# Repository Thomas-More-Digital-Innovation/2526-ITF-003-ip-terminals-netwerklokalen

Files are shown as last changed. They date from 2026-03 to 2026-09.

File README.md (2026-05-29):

# IP Terminals

This repository contains the configuration, CAD designs, and build system for custom IP Terminal images used in Thomas More network classrooms. Based on **NixOS**, these images provide a robust, immutable environment for network debugging and configuration, housed in a custom 3D-printed enclosure.

---

## 🖨️ Part 1: Hardware & 3D Printing

To assemble the physical IP Terminal housing, you can 3D print the enclosure components. The 3D model files are located in the [3d](./3d) directory.

### 📦 Print Components & Files
* **Main Enclosure / Case**: Use the **[3d/ip-terminal.stl](./3d/ip-terminal.stl)** model.
* **LCD Buttons**: Use the **[3d/1.44lcd_button_stick.STL](./3d/1.44lcd_button_stick.STL)** model for the LCD buttons.

---

## 🏗️ Part 2: Software & RPI Image Building

This part covers the setup, compilation, installation, and deployment of the custom NixOS-based operating system on the Raspberry Pi 4.

### 🚀 Key Features
- **Immutable Environment**: Root filesystem is read-only by default (stateless).
- **Network Tools**: Pre-installed `nmap`, `dnsutils`, `traceroute`, `netcat`, and more.
- **Custom Configuration**: A built-in `config` tool to manage network settings via TUI.
- **Hardware Integration**: Support for LCD displays and custom service for IP monitoring.
- **Remote Management**: SSH enabled by default (User: `cisco`, Password: `cisco`).

### 🛠️ Getting Started

#### 1. Install Nix
To build these images, you need the Nix package manager:
```bash
sh <(curl -L https://nixos.org/nix/install) --daemon
```

#### 2. Configure Nix
Enable Flakes and Cross-Compilation by adding the following to `/etc/nix/nix.conf`:
```text
experimental-features = nix-command flakes
extra-platforms = aarch64-linux arm-linux i686-linux
```

### 🏗️ Building the Image
You can build different variants of the SD card image using the Nix flake.
*NOTE: Building can take a while. Some packages are downloaded from Cachix and others are built from source.*

| Variant | Command |
| :--- | :--- |
| **Standard SD** | `nix build .#sdImages.rpi4 --print-build-logs` |
| **Uncompressed** | `nix build .#sdImages.rpi4-uncompressed --print-build-logs` |
| **Immutable** | `nix build .#sdImages.rpi4-immutable --print-build-logs` |
| **Immutable (Uncompressed)** | `nix build .#sdImages.rpi4-immutable-uncompressed --print-build-logs` |

### 💾 Flashing to SD Card
Once built, the image will be in `result/sd-image/`. Replace `/dev/sdX` with your SD card device path.

#### Using `dd` (Standard)
```bash
# For compressed images (.img.zst)
zstdcat result/sd-image/*.img.zst | sudo dd of=/dev/sdX bs=4M status=progress conv=fsync

# For uncompressed images (.img)
sudo dd if=result/sd-image/*.img of=/dev/sdX bs=4M status=progress conv=fsync
```

#### Other Methods
- **Manual Decompression**: `zstd -d result/sd-image/nixos* -o rpi4-nixos.img`
- **Using Caligula**: `sudo caligula burn result/sd-image/nixos*`

### 🔄 Updating
For testing purposes, you can update the terminals over the network without reflashing the SD card.
*NOTE: This is only possible for mutable images.*

#### Update (via ssh)
```bash
nixos-rebuild switch --flake .#rpi4 --target-host root@<IP_OR_HOSTNAME> --option filter-syscalls false
```

#### Update (via sshpass)
```bash
sshpass -p "cisco" nixos-rebuild switch --flake .#rpi4 --target-host root@<IP_OR_HOSTNAME> --option filter-syscalls false
```

#### Update for next boot (via sshpass)
```bash
sshpass -p "cisco" nixos-rebuild boot --flake .#rpi4 --target-host root@<IP_OR_HOSTNAME> --option filter-syscalls false
```

### 🔐 Configuration

#### Password Generation
If you need to update the `hashedPassword` in `flake.nix`, generate a new hash using:
```bash
mkpasswd -m sha-512
```

#### Default Credentials
- **Username**: `cisco` (or `root` for mutable images)
- **Password**: `cisco`

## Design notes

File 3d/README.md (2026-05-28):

## 3D files
Requires Autodesk Inventor 2026
STL Exports are pvovided

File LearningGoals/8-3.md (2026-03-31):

# 8.3 You automate system administration tasks with Linux service management

## 1. Project Overview
The IP Terminal is a rackmounted network appliance based on a Raspberry Pi 4. It features an integrated SPI display, three physical buttons, and a joystick. The primary goal of this device is to provide a dedicated hardware interface for managing the Pi's networking configuration (IPv4, IPv6, DHCP, and DNS) directly from the rack, without requiring an external keyboard, monitor, or SSH access.

## 2. NixOS on Raspberry Pi
For this project, I chose NixOS as the operating system. NixOS's declarative nature is ideal for building specialized appliances like the IP Terminal. The entire system state, from the Linux kernel and hardware overlays (like SPI for the display) to the Python application and systemd services is defined in a single configuration file (`flake.nix`). This ensures that the terminal's behavior is consistent, reproducible, and easy to redeploy.

### 2.1 Why Nix Flakes?
While traditional NixOS uses "channels" (stateful pointers to package sets), I used Nix Flakes for this project to achieve full reproducibility.

*   **Traditional NixOS**: Relies on `nix-channel`, which can differ between machines. Building the same configuration on two different days might result in different package versions if the channel was updated in between.
*   **Nix Flakes**: Uses a `flake.lock` file that pins every dependency (including `nixpkgs` and hardware overlays) to a specific git commit hash. This ensures that the terminal build is identical every single time, regardless of which machine it is built on or when the build occurs.

To ensure the IP Terminal is always functional and accessible upon booting the Raspberry Pi, I configured a **systemd service** within the NixOS configuration. This service automatically starts the Python-based control application, which manages the terminal's networking settings through the connected LCD and physical controls.

## 3. Defining the systemd Service in NixOS

In NixOS, services are defined declaratively in the configuration. The `systemd.services` option allows for a structured way to define how an application should run, its dependencies, and its lifecycle.

### 3.1 What is `multi-user.target`?
In systemd, **targets** act as synchronization points for the boot process, roughly equivalent to "runlevels" in older Linux systems.

The **`multi-user.target`** is the standard target for a system that is fully booted and ready to support multiple users, either via local login or network services (like SSH). It represents a stable, non-graphical multi-user environment. 

I configured the `ip-terminal` service to be pulled in by this target (via the `wantedBy` option), ensuring it starts automatically during the final phase of the normal boot sequence once core services are active.

### Service Configuration:
```nix
systemd.services.ip-terminal = {
  description = "IP Terminal Main Service";
  after = [ "network-online.target" ];
  wants = [ "network-online.target" ];
  path = with pkgs; [ networkmanager dialog ncurses ];
  serviceConfig = {
    Type = "simple";
    ExecStart = "/opt/venv/bin/python /opt/ip-terminal-code/main.py";
    WorkingDirectory = "/opt/ip-terminal-code";
    Environment = [
      "PYTHONUNBUFFERED=1"
      "FONT_PATH=${pkgs.dejavu_fonts}/share/fonts/truetype/DejaVuSans.ttf"
    ];
    Restart = "always";
    User = "root";
  };
  wantedBy = [ "multi-user.target" ];
};
```

### Key Components of the Service:
*   **`after` & `wants`**: The service waits for `network-online.target`, ensuring the networking stack is ready before the application attempts to read or modify settings via `nmcli`.
*   **`ExecStart`**: Points to the Python interpreter within a custom virtual environment (`/opt/venv/bin/python`) and executes the entry point of the application (`main.py`).
*   **`Restart = "always"`**: If the Python application crashes, systemd will automatically restart it.
*   **`User = "root"`**: This defines that the service will run as the root user, having full administrative privileges over the system. This is necessary because the application must interact with physical GPIO pins and use `nmcli` to modify system-wide network configuration.
*   **`Environment`**: This allows passing environment variables to the service. For the IP Terminal, I configured `PYTHONUNBUFFERED=1` to ensure that Python logs are sent immediately to `journalctl` without buffering, and `FONT_PATH` to tell the application where to find the fonts required for the LCD display.

## 4. The Python Application Logic

The application has multiple modes. When started by the systemd service (without arguments), it defaults to **Hardware Mode**, which utilizes the Waveshare LCD HAT and its joystick for input. However, it can also be run in **TUI Mode**, which uses the terminal for input and output.

### Application Entry Point:
```python
if __name__ == "__main__":
    parser = argparse.ArgumentParser(description="IP Terminal Configurator")
    parser.add_argument(
        "--tui",
        action="store_true",
        help="Run in TUI (dialog) mode instead of hardware mode.",
    )
    args = parser.parse_args()

    if args.tui:
        run_tui()
    else:
        run_hardware()
```

By running this as a systemd service, the terminal becomes a dedicated appliance. Users can configure the IP address, prefix, gateway, and DNS directly from the device's physical interface as soon as it powers on, without needing a keyboard or a network connection first.

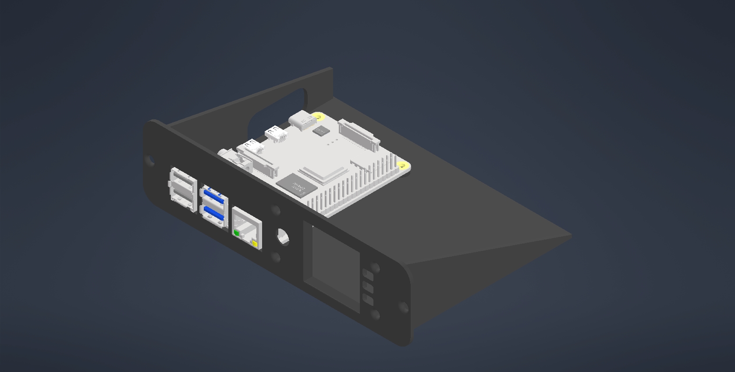
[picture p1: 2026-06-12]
3d/PI-RACK-MOUNT.jpg

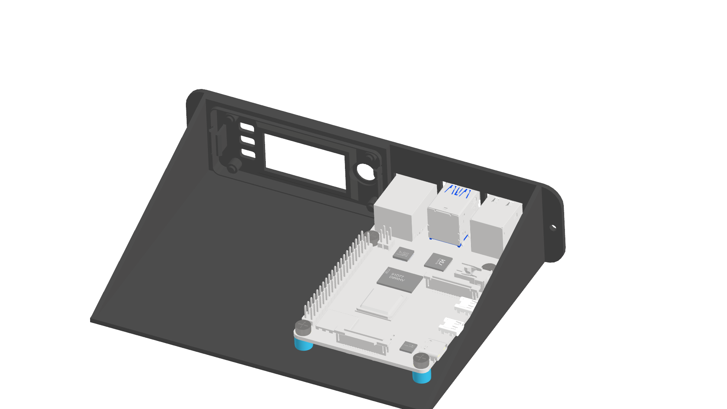
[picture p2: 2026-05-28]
3d/PI-RACK-MOUNT.png

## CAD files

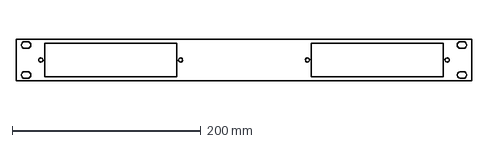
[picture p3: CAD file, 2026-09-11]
3d/WoodPanel.dxf
482.6 x 44.0 mm

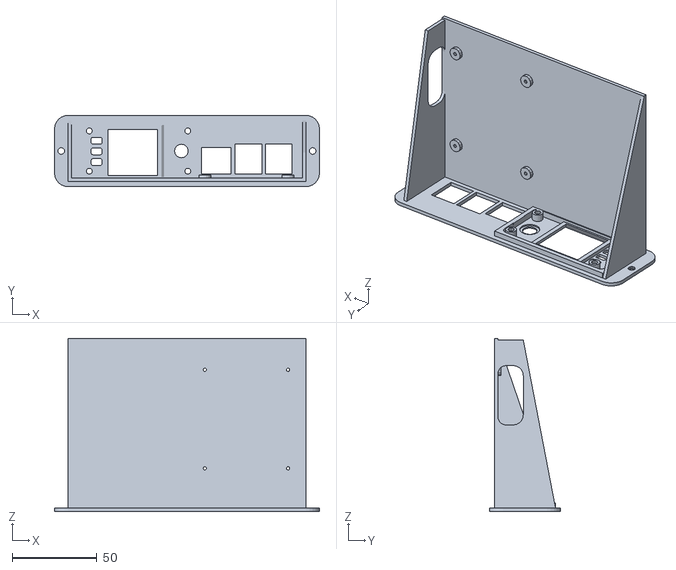
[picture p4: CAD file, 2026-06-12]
3d/ip-terminal.stl
156.0 x 42.0 x 102.0

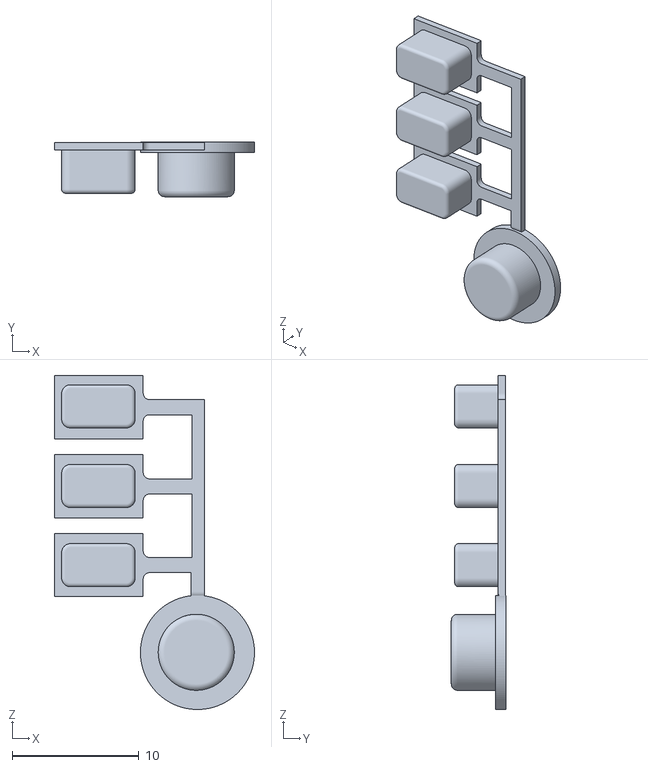
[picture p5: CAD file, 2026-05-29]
3d/1.44lcd_button_stick.STL
15.8 x 4.30 x 26.3

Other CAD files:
3d/1.44lcd_cap.ipt
3d/1.44lcd_cap_2.ipt
3d/Assembly1.iam
3d/Assembly2.iam
3d/BoltM3-PI-2.ipt
3d/BoltM3-PI.ipt
3d/M3 hex nut v6.ipt
3d/OldVersions/1.44lcd_cap.0003.ipt
3d/OldVersions/1.44lcd_cap_2.0016.ipt
3d/OldVersions/Assembly1.0021.iam
3d/OldVersions/Assembly2.0016.iam
3d/OldVersions/PI-RACK-MOUNT.0012.iam
3d/OldVersions/RPI_HOUSING2.0018.ipt
3d/OldVersions/Raspberry Pi 4 Model B.0001.iam
3d/OldVersions/Spacer.0002.ipt
3d/OldVersions/WoodPanel.0006.ipt
3d/PI-RACK-MOUNT.iam
3d/RPI_HOUSING2.ipt
3d/Raspberry Pi 4 Model B.iam
3d/Raspberry Pi 4 Model B.ipt
3d/Raspberry Pi 4 Model B/2.54 mm DUPONT MALE PIN HEADER, IO, 2X20, RPi4ModelB.ipt
3d/Raspberry Pi 4 Model B/2.54 mm DUPONT MALE PIN HEADER, IO, 2X20, RPi4ModelB_1.ipt
3d/Raspberry Pi 4 Model B/2.54 mm DUPONT MALE PIN HEADER, IO, 2X20, RPi4ModelB_10.ipt
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

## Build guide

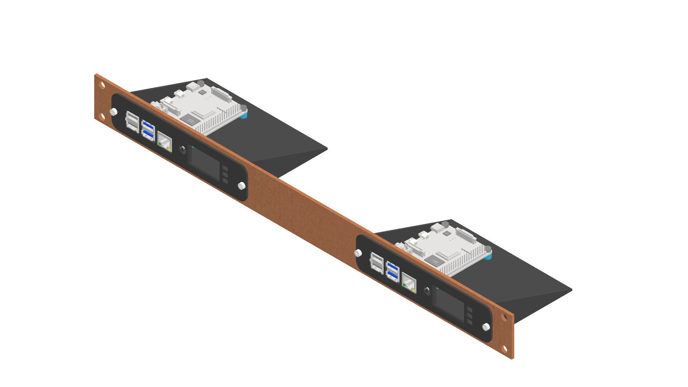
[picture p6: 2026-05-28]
3d/Assembly1.png

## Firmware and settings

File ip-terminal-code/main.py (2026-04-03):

#!/usr/bin/env python3
"""
IP Terminal Configurator

Two operating modes, selected at launch:
  (default)  Hardware mode – rotary encoder + I2C LCD (Raspberry Pi)
  --tui      TUI mode      – dialog-based interface for SSH / serial console

Usage:
  python3 main.py          # hardware mode
  python3 main.py --tui    # TUI mode
"""

import argparse
import ipaddress
import os
import subprocess
import sys
import textwrap
import time


# ---------------------------------------------------------------------------
# Shared state  (module-level so both modes can read/write it)
# ---------------------------------------------------------------------------

ip_octets      = [192, 168, 1, 1]
subnet_prefix  = 16                 # CIDR prefix length (0-32)
gateway_octets = [192, 168, 1, 1]
dns_octets     = [1,   1,   1, 1]
use_dhcp       = False              # True = ipv4.method auto

MENU_OPTIONS    = ["IP address", "Subnet prefix", "Gateway", "DNS"]
MENU_COUNT      = len(MENU_OPTIONS)
CONNECTION_NAME = "end0"
ipv6_method     = "auto"            # "auto", "dhcp", "manual", "disabled"
IPV6_METHODS    = ["auto", "dhcp", "manual", "disabled"]
IPV6_NAMES      = {
    "auto": "Automatic",
    "dhcp": "Automatic (DHCP only)",
    "manual": "Manual",
    "disabled": "Disabled"
}


# ---------------------------------------------------------------------------
# Shared helpers
# ---------------------------------------------------------------------------

def octets_str(octs):
    return ".".join(str(o) for o in octs)


def field_octets(field):
    """Return the mutable octet list for a field index (0=IP, 2=GW, 3=DNS)."""
    if field == 0:
        return ip_octets
    elif field == 2:
        return gateway_octets
    else:
        return dns_octets


def field_value_str(field):
    """Human-readable current value for a field index."""
    if field == 0:
        return "DHCP" if use_dhcp else octets_str(ip_octets)
    if field == 1:
        return "DHCP" if use_dhcp else f"/{subnet_prefix}"
    if field == 2:
        return "DHCP" if use_dhcp else octets_str(gateway_octets)
    return octets_str(dns_octets)  # field 3: DNS


def auto_gateway_from_ip():
    """Set gateway_octets to the first host address (network + 1) of the current subnet."""
    try:
        network = ipaddress.IPv4Network(
            f"{octets_str(ip_octets)}/{subnet_prefix}", strict=False
        )
        gw = network.network_address + 1
        gateway_octets[:] = list(gw.packed)
    except Exception:
        pass


# ---------------------------------------------------------------------------
# Network helpers (shared)
# ---------------------------------------------------------------------------

def get_network_settings():
    """Populate shared state from nmcli / systemd-resolved."""
    global subnet_prefix, use_dhcp, ipv6_method

    try:
        result = subprocess.run(
            ["nmcli", "-g", "IP4.ADDRESS", "connection", "show", CONNECTION_NAME],
            capture_output=True, text=True, check=True,
        )
        addr = result.stdout.strip().split("\n")[0]
        if addr and "/" in addr:
            ip_part, prefix_part = addr.split("/")
            ip_octets[:]  = [int(x) for x in ip_part.split(".")]
            subnet_prefix = int(prefix_part)
    except Exception as e:
        sys.stderr.write(f"Error in get_network_settings (IP4.ADDRESS): {e}\n")

    try:
        result = subprocess.run(
            ["nmcli", "-g", "IP4.GATEWAY", "connection", "show", CONNECTION_NAME],
            capture_output=True, text=True, check=True,
        )
        gw = result.stdout.strip()
        if gw and gw != "--":
            gateway_octets[:] = [int(x) for x in gw.split(".")]
    except Exception as e:
        sys.stderr.write(f"Error in get_network_settings (IP4.GATEWAY): {e}\n")

    try:
        # First try to get the configured static DNS
        result = subprocess.run(
            ["nmcli", "-g", "ipv4.dns", "connection", "show", CONNECTION_NAME],
            capture_output=True, text=True, check=True,
        )
        dns_output = result.stdout.strip()

        # If no static DNS, try the active runtime DNS (from DHCP)
        if not dns_output or dns_output == "--":
            result = subprocess.run(
                ["nmcli", "-g", "IP4.DNS", "connection", "show", CONNECTION_NAME],
                capture_output=True, text=True, check=True,
            )
            dns_output = result.stdout.strip()

        if dns_output and dns_output != "--":
            # nmcli may return multiple DNS servers separated by commas or spaces
            dns_str = dns_output.replace(",", " ").split()[0]
            if dns_str and "." in dns_str:
                dns_octets[:] = [int(x) for x in dns_str.split(".")]
    except Exception as e:
        sys.stderr.write(f"Error in get_network_settings (DNS recovery): {e}\n")

    try:
        result = subprocess.run(
            ["nmcli", "-g", "ipv4.method", "connection", "show", CONNECTION_NAME],
            capture_output=True, text=True, check=True,
        )
        use_dhcp = result.stdout.strip() == "auto"
    except Exception as e:
        sys.stderr.write(f"Error in get_network_settings (ipv4.method): {e}\n")

    try:
        result = subprocess.run(
            ["nmcli", "-g", "ipv6.method", "connection", "show", CONNECTION_NAME],
            capture_output=True, text=True, check=True,
        )
        meth = result.stdout.strip()
        if meth in IPV6_METHODS:
            ipv6_method = meth
    except Exception as e:
        sys.stderr.write(f"Error in get_network_settings (ipv6.method): {e}\n")


def get_live_ips():
    """Return a list of lines representing currently active IPv4 and IPv6 addresses."""
    lines = []
    for family, field in (("IPv4", "IP4.ADDRESS"), ("IPv6", "IP6.ADDRESS")):
        try:
            result = subprocess.run(
                ["nmcli", "-g", field, "connection", "show", CONNECTION_NAME],
                capture_output=True, text=True, check=True,
            )
            output = result.stdout.strip()
            if not output or output == "--":
                lines.append(f"{family}: (none)")
                continue

            # nmcli may return multiple addresses on multiple lines or separated by |
            raw_addrs = []
            for line in output.splitlines():
                raw_addrs.extend(line.split(" | "))

            addrs = [a.strip().replace("\\:", ":") for a in raw_addrs if a.strip()]
            if addrs:
                lines.append(f"{family}:")
                for a in addrs:
                    lines.append(f" - {a}")
            else:
                lines.append(f"{family}: (none)")
        except Exception:
            lines.append(f"{family}: error")
    return lines


def apply_all_settings():
    """Apply IP/prefix, gateway and DNS all at once."""
    ipv6_args = ["ipv6.method", ipv6_method]
    if ipv6_method != "manual":
        ipv6_args += ["ipv6.addresses", "", "ipv6.gateway", "", "ipv6.dns", "", "ipv6.ignore-auto-dns", "no"]

    if use_dhcp:
        dns_str = octets_str(dns_octets)
        subprocess.run(
            ["nmcli", "connection", "modify", CONNECTION_NAME,
             "ipv4.method", "auto",
             "ipv4.addresses", "",
             "ipv4.gateway", "",
             "ipv4.dns", dns_str,
             "ipv4.ignore-auto-dns", "yes"] + ipv6_args,
            check=True, capture_output=True,
        )
    else:
        cidr = f"{octets_str(ip_octets)}/{subnet_prefix}"
        dns_str = octets_str(dns_octets)
        subprocess.run(
            ["nmcli", "connection", "modify", CONNECTION_NAME,
             "ipv4.method", "manual",
             "ipv4.addresses", cidr,
             "ipv4.gateway", octets_str(gateway_octets),
             "ipv4.dns", dns_str,
             "ipv4.ignore-auto-dns", "yes"] + ipv6_args,
            check=True, capture_output=True,
        )
    subprocess.run(["nmcli", "con", "up", CONNECTION_NAME], check=True, capture_output=True)


def apply_settings(field):
    """Apply the current value of *field* via nmcli."""
    if field in (0, 1):
        if use_dhcp:
            subprocess.run(
                ["nmcli", "connection", "modify", CONNECTION_NAME,
                 "ipv4.method", "auto", "ipv4.addresses", "", "ipv4.gateway", "", "ipv4.dns", "", "ipv4.ignore-auto-dns", "no"],
                check=True, capture_output=True,
            )
        else:
            cidr = f"{octets_str(ip_octets)}/{subnet_prefix}"
            subprocess.run(
                ["nmcli", "connection", "modify", CONNECTION_NAME,
                 "ipv4.method", "manual", "ipv4.addresses", cidr],
                check=True, capture_output=True,
            )
        subprocess.run(["nmcli", "con", "up", CONNECTION_NAME], check=True, capture_output=True)

    elif field == 2:  # Gateway (static only – no-op in DHCP mode)
        if not use_dhcp:
            subprocess.run(
                ["nmcli", "connection", "modify", CONNECTION_NAME,
                 "ipv4.gateway", octets_str(gateway_octets)],
                check=True, capture_output=True,
            )
            subprocess.run(["nmcli", "con", "up", CONNECTION_NAME], check=True, capture_output=True)

    else:  # DNS (field 3)
        dns_str = octets_str(dns_octets)
        subprocess.run(
            ["nmcli", "connection", "modify", CONNECTION_NAME,
             "ipv4.dns", dns_str, "ipv4.ignore-auto-dns", "yes"],
            check=True, capture_output=True,
        )
        subprocess.run(["nmcli", "con", "up", CONNECTION_NAME], check=True, capture_output=True)


# ---------------------------------------------------------------------------
# Hardware mode  –  rotary encoder + I2C LCD
# ---------------------------------------------------------------------------
# ABCD
def run_hardware():
    """Main loop for the physical rotary-encoder + I2C-LCD interface."""
    global subnet_prefix, use_dhcp, ipv6_method

    import RPi.GPIO as GPIO
    from PIL import Image, ImageDraw, ImageFont
    from lcd_driver import ST7735

    # Pin assignments (Waveshare 1.44inch LCD HAT)
    UP_PIN    = 6
    DOWN_PIN  = 19
    LEFT_PIN  = 5
    RIGHT_PIN = 26
    PRESS_PIN = 13
    KEY1_PIN  = 21
    KEY2_PIN  = 20
    KEY3_PIN  = 16

    lcd = ST7735()

    # Load fonts (try environment variable first, then fall back to default)
    env_font = os.environ.get("FONT_PATH")
    font = ImageFont.load_default()
    title_font = font
    header_font = font

    if env_font:
        try:
            # Main font for menu items (increased from default ~8 to 13)
            font = ImageFont.truetype(env_font, 13)
            # Bold/Larger font for titles (15)
            title_font = ImageFont.truetype(env_font, 15)
            # Smaller header/footer if needed
            header_font = ImageFont.truetype(env_font, 11)
            print(f"DEBUG: Successfully loaded font from FONT_PATH: {env_font}")
        except Exception as e:
            print(f"DEBUG: Could not load TTF font from FONT_PATH ({env_font}), falling back to default.")
    else:
        print("DEBUG: FONT_PATH not set, falling back to default low-resolution font.")

    HW_MENU       = ["IPv4 Settings", "IPv6 Settings", "DNS Settings", "View IPs"]
    HW_MENU_COUNT = len(HW_MENU)
    IP_SUBMENU    = ["Mode", "IP Address", "Prefix", "Gateway", "Apply", "<- Back"]
    IPV6_SUBMENU  = ["Mode", "Apply", "<- Back"]

    # Local UI state
    mode             = "menu"   # "menu" | "ip_mode" | "view_ip" | "edit"
    menu_index       = 0
    edit_field       = 0        # field index into MENU_OPTIONS (0-3)
    state_index      = 0        # octet being edited (0-3)
    ip_mode_index    = 0
    ipv6_mode_index  = 0
    live_ip          = []       # List of (text, color) tuples
    view_ip_scroll   = 0
    edit_return_mode = "menu"

    # Color palette
    COLOR_BG      = (0, 0, 0)
    COLOR_TEXT    = (255, 255, 255)
    COLOR_HIGHLIGHT = (0, 0, 255) # Blue
    COLOR_ACCENT  = (0, 255, 255) # Cyan
    COLOR_YELLOW  = (255, 255, 0) # Yellow

    # ---- LCD helpers ----

    def update_display():
        image = Image.new("RGB", (128, 128), COLOR_BG)
        draw = ImageDraw.Draw(image)

        if mode == "menu":
            draw.text((5, 5), "Main Menu", font=title_font, fill=COLOR_ACCENT)
            draw.line((5, 23, 123, 23), fill=COLOR_ACCENT)
            for i, item in enumerate(HW_MENU):
                y = 28 + i * 20
                prefix = "> " if i == menu_index else "  "
                color = COLOR_HIGHLIGHT if i == menu_index else COLOR_TEXT
                draw.text((5, y), f"{prefix}{item}", font=font, fill=color)

        elif mode == "ip_mode":
            draw.text((5, 5), "IPv4 Settings", font=title_font, fill=COLOR_ACCENT)
            draw.line((5, 23, 123, 23), fill=COLOR_ACCENT)
            current_y = 28
            for i, item in enumerate(IP_SUBMENU):
                prefix = "> " if i == ip_mode_index else "  "
                color = COLOR_HIGHLIGHT if i == ip_mode_index else COLOR_TEXT

                display_text = item
                if i == 0: # Mode
                    display_text = f"Mode: {'DHCP' if use_dhcp else 'Manual'}"
                elif i in (1, 2, 3) and use_dhcp:
                    color = (100, 100, 100) # Grayed out
                lines = textwrap.wrap(f"{prefix}{display_text}", width=18)

                for j, line in enumerate(lines):
                    draw.text((5, current_y), line, font=font, fill=color)
                    current_y += 15 # Line height for font size 13

        elif mode == "ipv6_mode":
            draw.text((5, 5), "IPv6 Settings", font=title_font, fill=COLOR_ACCENT)
            draw.line((5, 23, 123, 23), fill=COLOR_ACCENT)
            current_y = 28
            for i, item in enumerate(IPV6_SUBMENU):
                prefix = "> " if i == ipv6_mode_index else "  "
                color = COLOR_HIGHLIGHT if i == ipv6_mode_index else COLOR_TEXT

                if i == 0: # Mode
                    label = f"{prefix}Mode:"
                    val_text = IPV6_NAMES.get(ipv6_method, ipv6_method)
                    lines = [label]
                    # Indent the value lines
                    wrapped_val = textwrap.wrap(val_text, width=14)
                    for w_line in wrapped_val:
                        lines.append(f"    {w_line}")
                else:
                    display_text = item
                    lines = textwrap.wrap(f"{prefix}{display_text}", width=18)

                for line in lines:
                    draw.text((5, current_y), line, font=font, fill=color)
                    current_y += 15

        elif mode == "view_ip":
            draw.text((5, 5), "IP Addresses", font=title_font, fill=COLOR_ACCENT)
            draw.line((5, 23, 123, 23), fill=COLOR_ACCENT)

            # Draw up to 7 lines from the scroll position
            for i in range(7):
                idx = view_ip_scroll + i
                if idx >= len(live_ip):
                    break
                line, color = live_ip[idx]
                y = 28 + i * 12
                draw.text((5, y), line, font=header_font, fill=color)

            draw.text((5, 115), "Press=Exit, +/-=Scroll", font=header_font, fill=COLOR_HIGHLIGHT)

        elif mode == "edit":
            labels = {0: "Edit IP", 1: "Edit prefix", 2: "Edit GW", 3: "Edit DNS"}
            draw.text((5, 5), labels[edit_field], font=title_font, fill=COLOR_ACCENT)
            draw.line((5, 23, 123, 23), fill=COLOR_ACCENT)

            if edit_field == 1:
                draw.text((5, 50), f"Value: /{subnet_prefix}", font=font, fill=COLOR_TEXT)
            else:
                octs = field_octets(edit_field)
                val_str = ""
                for i, o in enumerate(octs):
                    if i == state_index:
                        val_str += f"[{o}] "
                    else:
                        val_str += f"{o} "
                draw.text((5, 50), val_str.strip(), font=font, fill=COLOR_TEXT)

            draw.text((5, 105), "Press to confirm", font=header_font, fill=COLOR_HIGHLIGHT)

        print(f"DEBUG: update_display (mode={mode}, menu={menu_index}, edit={edit_field})")
        lcd.display(image)

    def do_apply_all():
        image = Image.new("RGB", (128, 128), COLOR_BG)
        draw = ImageDraw.Draw(image)
        draw.text((5, 50), "Applying...", font=font, fill=COLOR_ACCENT)
        lcd.display(image)

        try:
            apply_all_settings()
            draw.text((5, 80), "Done!", font=font, fill=(0, 255, 0))
            lcd.display(image)
            time.sleep(2)
        except Exception as exc:
            print(f"apply error: {exc}")
            draw.text((5, 75), "Error!", font=font, fill=(255, 0, 0))
            err_msg = str(exc)[:22]
            draw.text((5, 95), err_msg, font=header_font, fill=(255, 0, 0))
            lcd.display(image)
            time.sleep(3)

    # ---- GPIO setup ----
    GPIO.setmode(GPIO.BCM)
    for pin in [UP_PIN, DOWN_PIN, LEFT_PIN, RIGHT_PIN, PRESS_PIN, KEY1_PIN, KEY2_PIN, KEY3_PIN]:
        GPIO.setup(pin, GPIO.IN, pull_up_down=GPIO.PUD_UP)

    get_network_settings()
    update_display()
    print("IP configurator ready. Joystick to navigate, KEY1/Press to select.")

    display_dirty    = False

    def get_input_state():
        return {
            "up": GPIO.input(UP_PIN) == 0,
            "down": GPIO.input(DOWN_PIN) == 0,
            "left": GPIO.input(LEFT_PIN) == 0,
            "right": GPIO.input(RIGHT_PIN) == 0,
            "press": GPIO.input(PRESS_PIN) == 0,
            "key1": GPIO.input(KEY1_PIN) == 0,
            "key2": GPIO.input(KEY2_PIN) == 0,
            "key3": GPIO.input(KEY3_PIN) == 0,
        }

    last_input = get_input_state()

    up_hold_start = 0
    up_last_repeat = 0
    down_hold_start = 0
    down_last_repeat = 0

    REPEAT_DELAY = 0.4

    try:
        while True:
            current_input = get_input_state()
            now = time.time()

            # Detect edge (button press)
            press_detected = False
            key3_detected = False
            direction = 0
            back_detected = False
            left_detected = False
            right_detected = False

            # UP with repeat and acceleration
            if current_input["up"]:
                if not last_input["up"]:
                    direction = -1
                    up_hold_start = now
                    up_last_repeat = now
                    print("DEBUG: Joystick UP (press)")
                elif now - up_hold_start > REPEAT_DELAY:
                    hold_duration = now - up_hold_start
                    # Accelerate interval and step
                    if hold_duration > 1.5:
                        current_interval = 0.05
                        direction = -20
                    elif hold_duration > 0.2:
                        current_interval = 0.04
                        direction = -5
                    else:
                        current_interval = 0.1
                        direction = -1

                    if now - up_last_repeat > current_interval:
                        up_last_repeat = now
                        # direction is already set
                    else:
                        direction = 0 # Don't act if interval not reached
            else:
                up_hold_start = 0

            # DOWN with repeat and acceleration
            if current_input["down"]:
                if not last_input["down"]:
                    direction = 1
                    down_hold_start = now
                    down_last_repeat = now
                    print("DEBUG: Joystick DOWN (press)")
                elif now - down_hold_start > REPEAT_DELAY:
                    hold_duration = now - down_hold_start
                    # Accelerate interval and step
                    if hold_duration > 3:
                        current_interval = 0.05
                        direction = 10
                    elif hold_duration > 1.5:
                        current_interval = 0.04
                        direction = 5
                    else:
                        current_interval = 0.1
                        direction = 1

                    if now - down_last_repeat > current_interval:
                        down_last_repeat = now
                        # direction is already set
                    else:
                        direction = 0 # Don't act if interval not reached
            else:
                down_hold_start = 0

            if current_input["left"] and not last_input["left"]:
                left_detected = True
                print("DEBUG: Joystick LEFT")
            if current_input["right"] and not last_input["right"]:
                right_detected = True
                print("DEBUG: Joystick RIGHT")

            if current_input["press"] and not last_input["press"]:
                press_detected = True
                print("DEBUG: Joystick PRESS")
            if current_input["key1"] and not last_input["key1"]:
                direction = -1
                print("DEBUG: KEY1 (UP)")
            if current_input["key2"] and not last_input["key2"]:
                direction = 1
                print("DEBUG: KEY2 (DOWN)")
            if current_input["key3"] and not last_input["key3"]:
                key3_detected = True
                print("DEBUG: KEY3 (Quick Action)")
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

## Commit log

2026-03-06 Enable I2C
2026-05-28 Upload 3D files
    [1.44lcd_cap.0003.ipt, 1.44lcd_cap_2.0014.ipt, 2.54 mm DUPONT MALE PIN HEADER, IO, 2X20, RPi4ModelB.ipt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]
2026-05-29 Add LCD buttons
    [1.44lcd_button_stick.STL]
2026-05-29 Make display hole bottom bigger and add chamfers
    [1.44lcd_cap_2.0014.ipt, 1.44lcd_cap_2.0016.ipt, 1.44lcd_cap_2.ipt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]
2026-06-09 Make it fit with POE hat
    [Assembly1.0020.iam, Assembly1.0021.iam, Assembly1.iam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]
2026-06-12 Update exports
    [ip-terminal.stl]
